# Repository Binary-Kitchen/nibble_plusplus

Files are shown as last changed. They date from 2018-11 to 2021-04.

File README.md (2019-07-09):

# Nibble++
A simple PCB to test your SMD hand-soldering skills. Going down to sand grain sized 01005 SMD parts, this button is a challenge for experienced "soldiers" and those who want to become one.

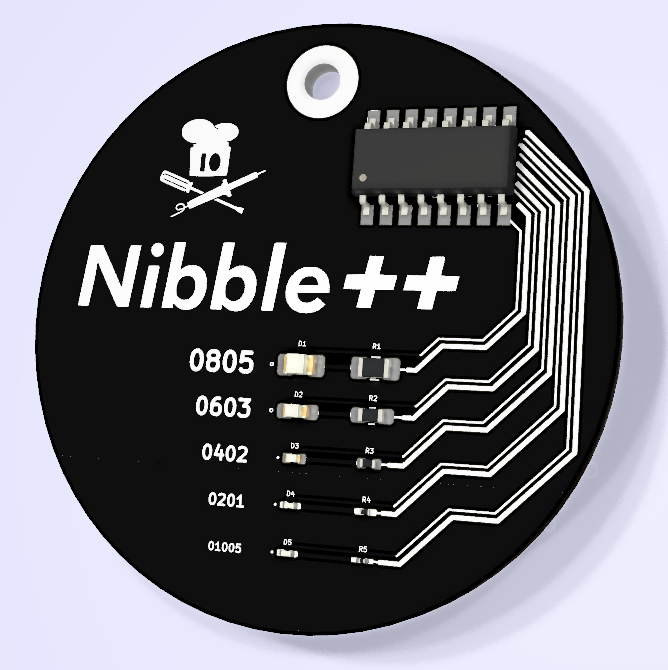
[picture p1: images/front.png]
Nibble++ front


## Bill of Material
| Designator | Package | Quantity | Designation |
|:---:|:---:|---|:---:|
| BT1 | SMD Battery Holder | 1 | CR2023 |
| C1 | 0805 SMD Capacitor | 1 | 100n F |
| C2 | 0805 SMD Capacitor | 1 | 1µ F |
| C3 | 0805 SMD Capacitor | 1 | 100n F |
| D1 | 0805 SMD LED | 1 | LED Red |
| D2 | 0603 SMD LED | 1 | LED Orange |
| D3 | 0402 SMD LED | 1 | LED Yellow |
| D4 | 0201 SMD LED | 1 | LED Green |
| D5 | 0201 SMD LED | 1 | LED Blue |
| R1 | 0805 SMD Resistor  | 1 |  82 Ohm |
| R2 | 0603 SMD Resistor  | 1 |  82 Ohm |
| R3 | 0402  SMD Resistor | 1 |  62 Ohm |
| R4 | 0201 SMD Resistor  | 1 | 330 Ohm |
| R5 | 01005 SMD Resistor | 1 |  33 Ohm |
| R6,R7 | 0805 SMD Resistor  | 2 | 100k Ohm |
| SW1 | SMD Switch | 1 | |
| U1 | SOIC-8 NE555 | 1 | |
| U2 | SOP-16 CD4017 | 1 | |

## Manual
TBD
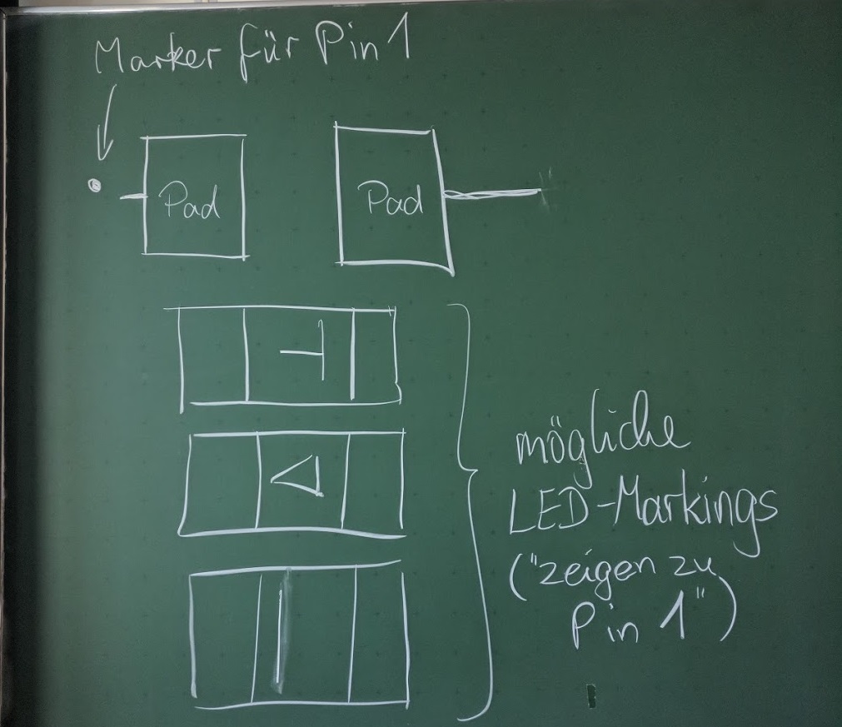
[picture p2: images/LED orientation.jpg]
LED Orientation on PCB


## Idea
The Idea origins to Ken Olsen and his Attiny SMD Challenge. Many thanks to Ken Olsen for the idea and for opening up this great work to creative commons.

## Name
The name Nibble++ origins from a simple [nibble peg](https://github.com/Binary-Kitchen/SolderingTutorial/tree/master/NibblePegDIP) which has been developed one year earlier. A Nibble is a unit for the amount of 4 bits (https://en.wikipedia.org/wiki/Nibble). Because we are using five LEDs we incremented the value ;).

## Copyright and Authorship
- Idea: [CC-BY-SA 3.0](https://creativecommons.org/licenses/by-sa/3.0/) - [Ken Olsen (www.MakersBox.us)](https://github.com/aspro648/KiCad/tree/master/projects/Attiny/Attiny85Challenge)
- PCB-Layout: [CC-BY-SA 3.0](https://creativecommons.org/licenses/by-sa/3.0/) - [Ken Olsen](http://www.MakersBox.us), [Thomas Schmid and Timo Schindler](https://www.binary-kitchen.de)
- Manual (TeX): [LPPL](https://www.latex-project.org/lppl.txt) - [Marei Peischl](https://peitex.de)
- Manual (pdf): [CC-BY-SA 4.0](https://creativecommons.org/licenses/by-sa/4.0/) - [Binary Kitchen e.V.](https://www.binary-kitchen.de)

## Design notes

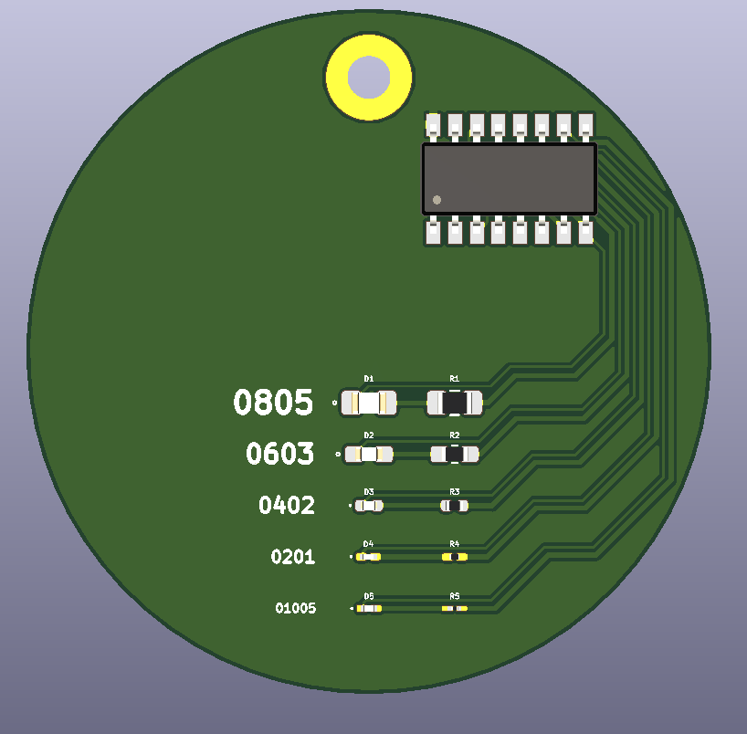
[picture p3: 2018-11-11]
images/empty_render.png

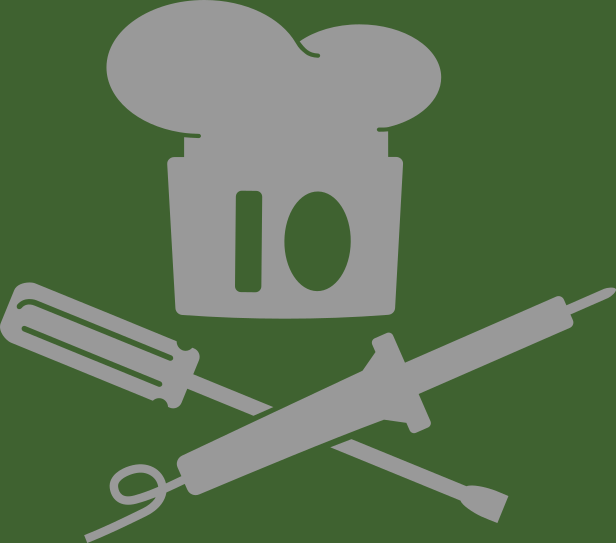
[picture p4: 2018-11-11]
images/g1466.png

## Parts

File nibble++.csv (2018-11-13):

Id | Designator | Package | Quantity | Designation
1 | R2 | 0603 SMD Resistor | 1 | 100 Ohm
2 | R1 | 0805 SMD Resistor | 1 | 100 Ohm
3 | C1 | 0805 SMD Capacitor | 1 | 100n
4 | C2 | 0805 SMD Capacitor | 1 | 1µ F
5 | C3 | 0805 SMD Capacitor | 1 | 100n F
6 | D3 | 0402 SMD LED | 1 | 0402 LED Yellow
7 | R6,R7 | 0805 SMD Resistor | 2 | 100k Ohm
8 | U1 | SOIC-8 NE555 | 1
10 | R3 | 0402 SMD Resistor | 1 | 100 Ohm
13 | BT1 | SMD Battery Holder | 1 | CR2023
14 | D1 | 0805 SMD LED | 1 | LED Red
15 | D2 | 0603 SMD LED | 1 | LED Orange
16 | D4 | 0201 SMD LED | 1 | LED Green
17 | D5 | 0201 SMD LED | 1 | LED Blue
18 | R4 | 0201 SMD Resistor | 1 | 150 Ohm
19 | R5 | 01005 SMD Resistor | 1 | 200 Ohm
20 | SW1 | SMD Switch | 1
21 | U2 | SOP-16 CD4017 | 1

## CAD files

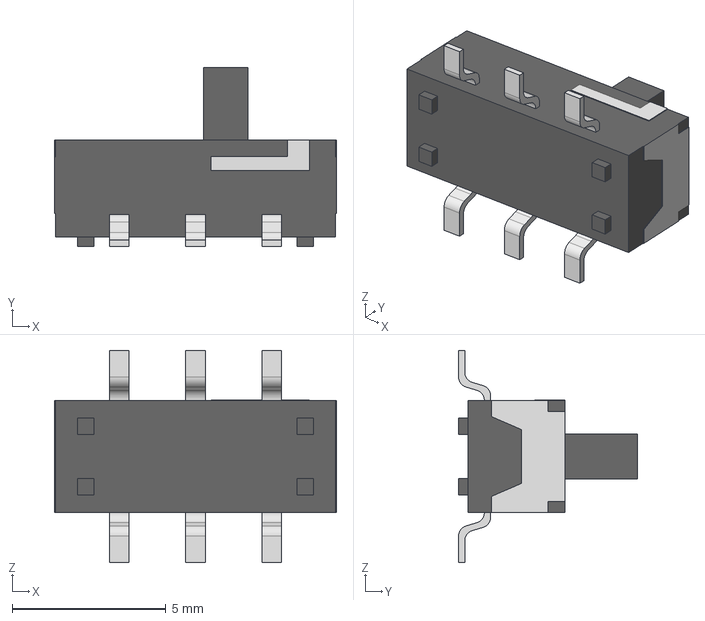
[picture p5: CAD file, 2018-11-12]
3d-models/Selector Switch - MSS22D18.stp
9.17 x 5.82 x 6.91 mm

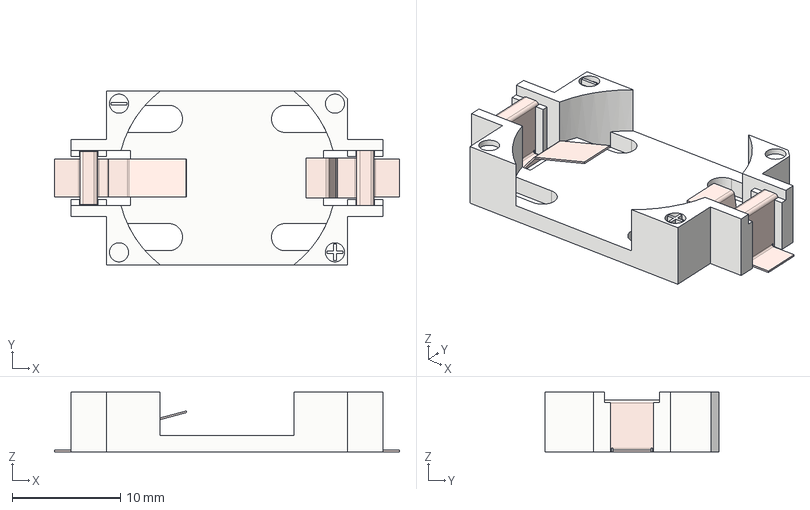
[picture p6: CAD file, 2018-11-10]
3d-models/CR2032 holder.step
31.8 x 16.0 x 5.50 mm
base
connector_plus
connector_minus

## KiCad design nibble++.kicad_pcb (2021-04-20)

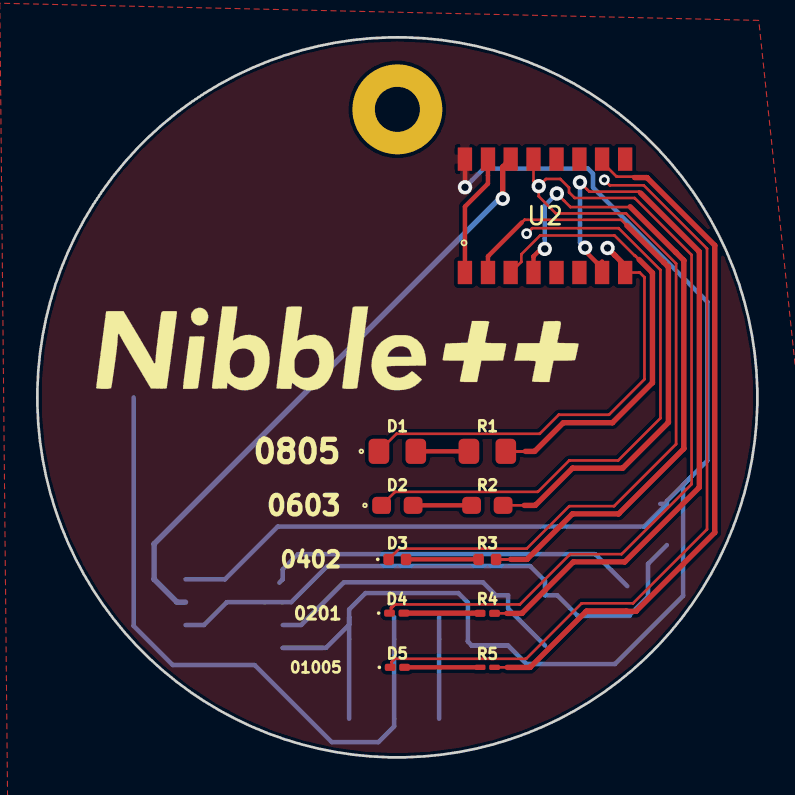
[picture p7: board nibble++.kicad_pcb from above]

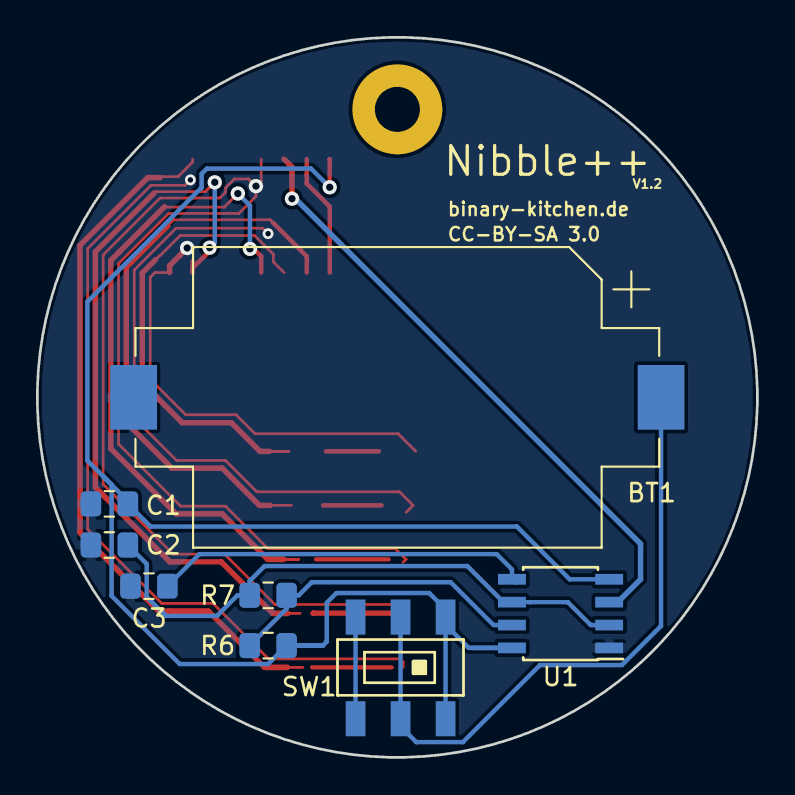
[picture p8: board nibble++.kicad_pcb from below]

Board: 2 copper layers, 40.0 x 40.0 mm, 19 parts (8 on the bottom side), 18 nets.

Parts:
BT1: CR2023; BatteryHolder_Keystone_1060_1x2032
C1: 100n; C_0805_2012Metric_Pad1.15x1.40mm_HandSolder
C2: 1µ F; C_0805_2012Metric_Pad1.15x1.40mm_HandSolder
C3: 100n F; C_0805_2012Metric_Pad1.15x1.40mm_HandSolder
D1: 0805 LED Red; LED_0805_2012Metric_Pad1.15x1.40mm_HandSolder_simple_drawing
D2: 0603 LED Orange; LED_0603_1608Metric_Pad1.05x0.95mm_HandSolder_simple_drawing
D3: 0402 LED Yellow; LED_0402_1005Metric
D4: 0201 LED Green; LED_0201_0603Metric_hand_soldering
D5: 0201 LED Blue; LED_0201_0603Metric_hand_soldering
R1: 100 Ohm; R_0805_2012Metric_Pad1.15x1.40mm_HandSolder
R2: 100 Ohm; R_0603_1608Metric_Pad1.05x0.95mm_HandSolder
R3: 100 Ohm; R_0402_1005Metric
R4: 150 Ohm; R_0201_0603Metric_hand_soldering
R5: 200 Ohm; R_01005_0402Metric_hand_soldering
R6, R7: 100k Ohm; R_0805_2012Metric_Pad1.15x1.40mm_HandSolder
SW1: SW_DPDT_x2; smd_switch_slide
U1: NE555; SOIC-8_3.9x4.9mm_P1.27mm
U2: 4017; SOP-16_4.4x10.4mm_P1.27mm_simple_drawing

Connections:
+3V3: BT1.1, SW1.2
GND: BT1.2, C1.1, C2.1, C3.2, D1.1, D2.1, D3.1, D4.1, D5.1, U1.1, U2.8, U2.13
unnamed: C2.2, R7.2, U1.2, U1.6
unnamed: C3.1, U1.5
unnamed: D1.2, R1.1
unnamed: D2.2, R2.1
unnamed: D3.2, R3.1
unnamed: D4.2, R4.1
unnamed: D5.2, R5.1
unnamed: R1.2, U2.3
unnamed: R2.2, U2.2
unnamed: R3.2, U2.4
unnamed: R4.2, U2.7
unnamed: R5.2, U2.10
unnamed: R6.2, R7.1, U1.7
unnamed: U1.3, U2.14
unnamed: U2.1, U2.15
VS: C1.2, R6.1, SW1.1, U1.4, U1.8, U2.16

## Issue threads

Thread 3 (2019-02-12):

Recalculate resistor value

marove2000, 2019-02-12:
Some LEDs are too bright, some are too faint.

ventilator, 2019-07-08:
I made some measurement on a baseline of I=0.9mA for the red LED, then tuned the other LEDs to the same brightness. Brightness was measured with my eyes, so it is a bit subjective.

  | Measurement |   |   | |Calculated  |  E12
-- | -- | -- | -- | -- | -- | --
  | U (V) | I (mA) | R now (Ohm) | U r (V) | R future (Ohm) |  
rot | 1,80 | 0,9 | 82 | 1,20 | 83 | 82 | baseline
orange | 1,86 | 0,9 | 82 | 1,14 | 79 | 82 |  
gelb | 1,91 | 1,1 | 100 | 1,09 | 62 | 62 |  
grün | 2,15 | 0,16 | 150 | 0,85 | 332 | 330 | very bright led
blue | 2,57 | 0,9 | 200 | 0,43 | 30 | 33 |  
  |   |   |   |   |   |   |  
  |   |   |   |   |   |   |  
Battery | 3 | V |   |   |   |   |  
Scaling factor | 16 |   |   |   |   |   |  

Scaling factor means   that measurement was done at steady state, but LED flashes in application

Basically I scaled   the 0,9mA baseline current for red to the acutal 82 Ohm used in application

Anyway, I recommend resistors as shown in the last column, rounded to the E12 line

marove2000, 2019-07-09:
fixed. Thank you for the calculation.

Closed 2019-07-09.

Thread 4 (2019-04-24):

Move C1 and C2

marove2000, 2019-04-24:
The capacitors should have a greater distance to the CR2032 battery holder. People sometimes solder a wrong capacitor and can not replace them anymore with attached CR2032 battery holder.

Closed 2021-04-20.

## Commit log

2018-11-10 inital commit
    [CR2032 holder.step, SMD-Challange.kicad_pcb, SMD-Challange.sch]
2018-11-10 Update .gitignore and apply changes to the repo
    [CR2032 holder.step]
2018-11-10 managed to layout without visible via
    [SMD-Challange.kicad_pcb]
2018-11-11 update component values for ne555 oscillator
    Frequency is now 4.8 Hz
    [SMD-Challange.sch]
2018-11-11 cleanup schematic and add title
    [SMD-Challange.sch]
2018-11-11 added custom footprints for smd 0201 and 01005 for hand-soldering
    [SMD-Challange.kicad_pcb, SMD-Challange.sch]
2018-11-11 changed some footprints and made the surface printing nicer
    [SMD-Challange.kicad_pcb, SMD-Challange.sch]
2018-11-11 added line in front mask layer
    [SMD-Challange.kicad_pcb]
2018-11-11 remove some silkscreen lines
    [SMD-Challange.kicad_pcb]
2018-11-11 finish design of nibble++ :)
    [SMD-Challange.kicad_pcb]
2018-11-12 Changed track-layout slightly for better soldering
    [SMD-Challange.kicad_pcb]
2018-11-12 add 3d model of on-off-switch
    [SMD-Challange.kicad_pcb, Selector Switch - MSS22D18.stp]
2018-11-12 add logo to site layout and update description
    [SMD-Challange.sch]
2018-11-12 remove some silkscreen features and cleanup layout
    [SMD-Challange.kicad_pcb, SMD-Challange.sch]
2018-11-12 Renamed project to nibble++
    [nibble++.kicad_pcb, nibble++.sch]
2018-11-12 fixed overlaying routes
    [nibble++.kicad_pcb]
2018-11-13 added additional information for some parts
    [nibble++.kicad_pcb, nibble++.sch]
2018-11-13 generated simple BOM
    [nibble++.csv]
2018-11-13 updated README.md with BOM
2018-12-18 fixed too small labelling and some lines
    [nibble++.kicad_pcb]
2019-01-07 adjusted thickness of drawing
    [nibble++.kicad_pcb]
2019-01-07 Change routing on the visible tracks
    [nibble++.kicad_pcb]
2019-01-07 bump version number
    [nibble++.kicad_pcb]
2019-01-07 add gerber files
    [nibble++-B.Cu.GBL, nibble++-B.Mask.GBS, nibble++-B.SilkS.GBO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]
2019-04-28 add LED orientation on PCB image
2019-07-09 modified resistor value. fixing #3
    [nibble++.sch]
2021-04-20 replaced gerber files
    [nibble++-B.Cu.GBL, nibble++-B.Mask.GBS, nibble++-B_Cu.gbr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]
2021-04-20 fixed #4
    [nibble++.kicad_pcb]
